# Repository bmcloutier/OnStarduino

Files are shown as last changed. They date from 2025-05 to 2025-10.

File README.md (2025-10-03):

# OnStarduino

#### Designed to appear as a retro-styled radio, this Arduino-powered dashboard displays data about my Chevy Bolt EV and lets me remotely start the car, unlock doors, and more!

Retro-styled portable cassette player OnStarduino

- The glowing tuner needle shows the battery level, and pulses if the car is charging.
- VU meter displays the current charging voltage of 120, 240, or 400 volts.
- Counter resets when data is refreshed and increments each hour thereafter.
- Buttons for play/rewind/etc send commands to remote start the car, unlock doors, flash lights, etc.
- Tape spins when a command is in progress, and the activity LED will blink SOS if the command fails.
- Toggle button enables an SMS reminder if the car isn't plugged in at 9PM.
- Slider controls the speaker volume, the knob adjusts LED brightness.
- Antenna is for aesthetics only!

<br>

## Project Highlights

- Communicates with the OnStar API to send commands and receive diagnostics. A separate VoIP API is used to send SMS notifications.
- Pseudo-multitasking allows concurrent tasks without a Real-Time OS (RTOS) on limited Arduino hardware.
- Several electro-mechanical features for inputs (keys and dials), outputs (LEDs and motors), and sensing (hall-effect rotary encoding).
- Designed in Fusion 360, 3D printed at home, assembled using mostly off-the-shelf electronics and one custom laser-cut part.

Special thanks to samrum for their work on the [OnStarJS](https://github.com/samrum/OnStarJS) library. It was instrumental in helping me understand the mechanics of the OnStar API.

[Icon artwork by Noah Jacobus](https://www.svgrepo.com/collection/chunk-16px-thick-interface-icons/)

<br>

## Minimum Install Requirements

:warning: **WARNING: This is an unofficial implementation of the OnStar API, use at your own risk.**

- An active [OnStar Connect](https://www.onstar.com/plans/connect) subscription and associated vehicle.
- An active [VoIP.ms](https://voip.ms/) account with a Direct Inward Dial (DID) number that support SMS ($0.99/month + $0.0075/SMS)
- [Arduino Nano ESP32](https://store.arduino.cc/products/nano-esp32) or similar Single Board Computer (SBC) with the following features:
  - WiFi
  - EEPROM with 2kB
  - 16 GPIO pins (4 must support PWM)
- Installed libraries:
  - [EEPROM](https://docs.arduino.cc/learn/built-in-libraries/eeprom/)
  - [ESP32Servo](https://madhephaestus.github.io/ESP32Servo/classServo.html)
  - [TimeLib](https://playground.arduino.cc/Code/Time/)
  - [WiFiClientSecure](https://github.com/pamelacece/WiFiClientSecure)
- Included `secrets.h`:

```cpp
#define SECRET_WIFI_SSID "aaa" // WiFi network name
#define SECRET_WIFI_PASS "bbb" // WiFi network password
#define SECRET_SMS_USER "someone@example.com" // VoIP.ms username
#define SECRET_SMS_PASS "password1" // VoIP.ms API password (not account password)
#define SECRET_SMS_DID "1234567890" // VoIP.ms DID number
#define SECRET_SMS_DST "9876543210" // Phone number to receive SMS notifications
#define SECRET_VIN "ccc" // Vehicle Identification Number (VIN) of your vehicle
#define SECRET_VID "hhh" // Vehicle Id from GM
#define SECRET_DEVICE_ID "dddddddd-dddd-dddd-dddd-dddddddddddd" // Random Version 4 UUID from https://www.uuidgenerator.net/version4
#define SECRET_CLIENT_REQUEST_ID "eeeeeeee-eeee-eeee-eeee-eeeeeeeeeeee" // Found in header of https request to custlogin.gm.com
#define SECRET_CLIENT_ID "ffffffff-ffff-ffff-ffff-ffffffffffff" // Found in body of https request to custlogin.gm.com
#define SECRET_REFRESH_TOKEN "ggg\0" // ~1650 character token found in https response from custlogin.gm.com
```

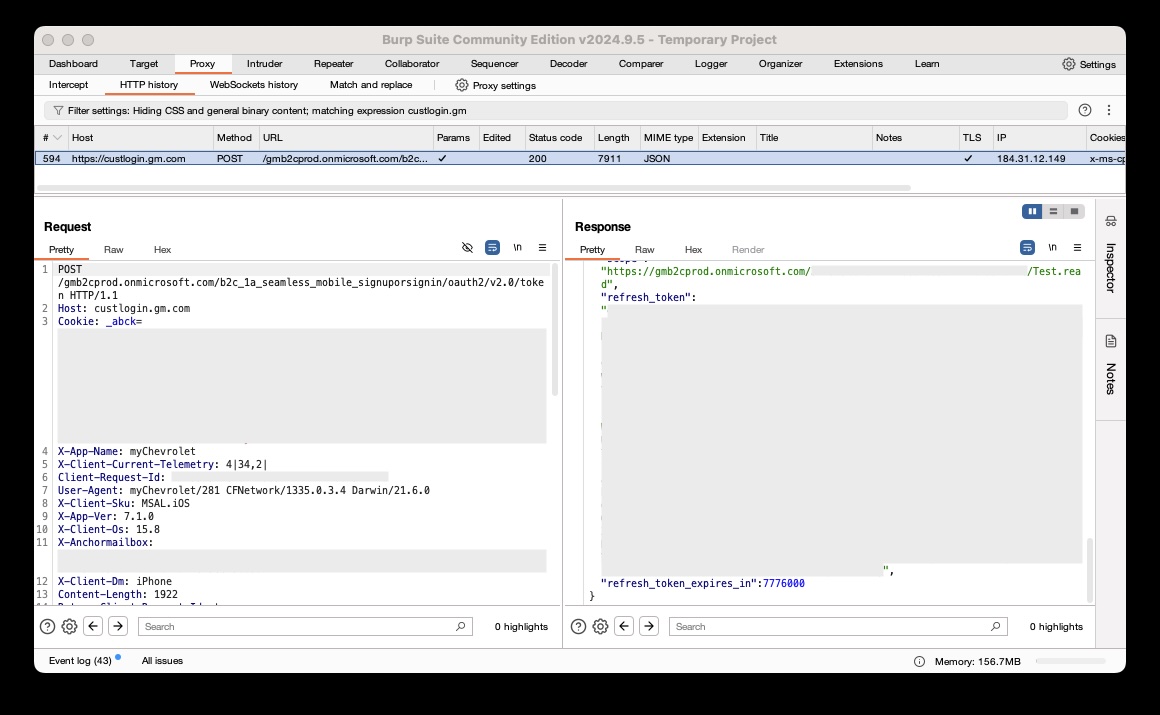
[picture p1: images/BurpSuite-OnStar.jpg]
Screenshot of Burp Suite interface
The last three secrets can be found by monitoring network traffic between the official Chevrolet app and custlogin.gm.com using a tool such as [Burp Suite](https://portswigger.net/). The critical request to custlogin.gm.com appears to occur only once an hour when the `subject_token` expires. Similarly, you can obtain your vehicle ID by monitoring traffic to eve-vcn.ext.gm.com.

<br>

## Component Details

### Tuner/Battery Level

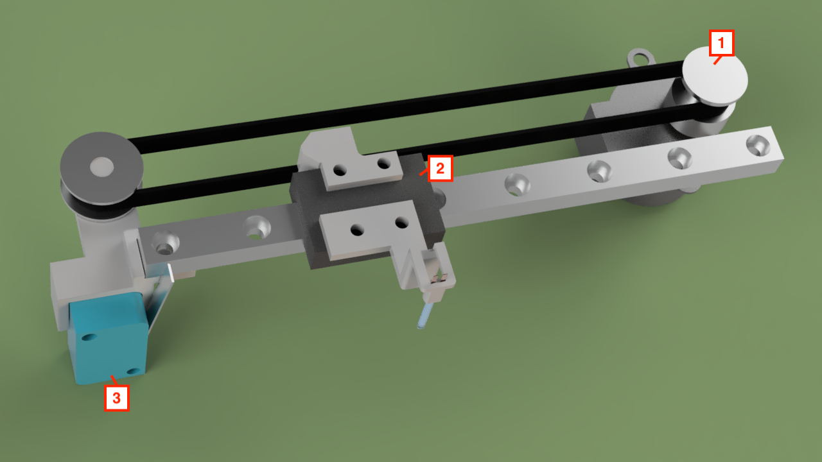
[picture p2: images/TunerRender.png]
Render of tuner mechanism
The tuner display is the easiest to read, even from across the room, so it shows the most important data: battery level. To move the tuner needle, a stepper motor rotates a pulley gear [1] attached to a belt, which moves the rail carriage [2] and the needle. The stop switch [3] is used to home the carriage at startup.

Moving an actual, physical object takes time, even if it's just turning a gear a fraction of a degree. Since the CPU will always outrun the motor, it's important to program delays to allow the motor to catch up. The following code moves the needle to the 0% battery position during setup, and includes a `stepperCooldown` variable that can be tweaked as needed. It turns out 2ms is the lowest whole millisecond that works; 1ms just makes the motor vibrate in a disconcerting way.

```cpp
for (int f = 0; f < 220; f++) {
  stepOnce(1);
  delay(stepperCooldown);
}
```

<br>

### Cassette Tape/Command in Progress

The radio wouldn't be complete without a tape player. I wanted its movement related to the command keys in some way, and eventually decided the tape should spin to indicate that a command is being processed. When it stops, you're clear to send another command.

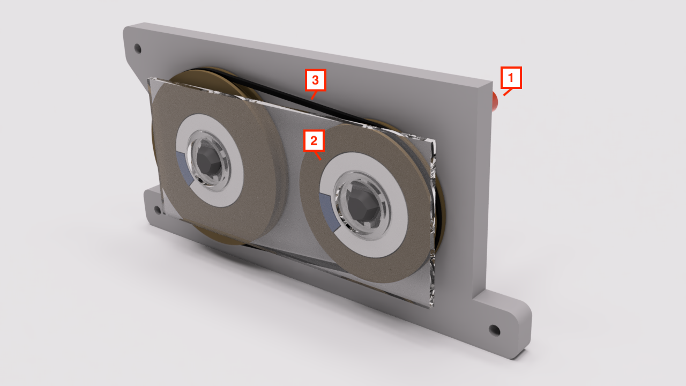
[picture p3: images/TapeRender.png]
Render of tape mechanism
A mini motor in the back [1] spins the right wheel [2]. A thin belt [3] connects the right wheel to the left. The wheels are different sizes, making them spin at slightly different rates for a realistic effect. The clear plastic is harvested from an actual tape since it's nearly impossible to 3D print crystal-clear objects.

<br>

### Tape Counter/Refresh Counter

Next to the tape player you'll often find a tape counter. On this radio it represents how many hours have elapsed since the last data refresh. Technically it increments on the hour like a cuckoo clock because the motor is a bit loud and having it run at random times was unacceptable.

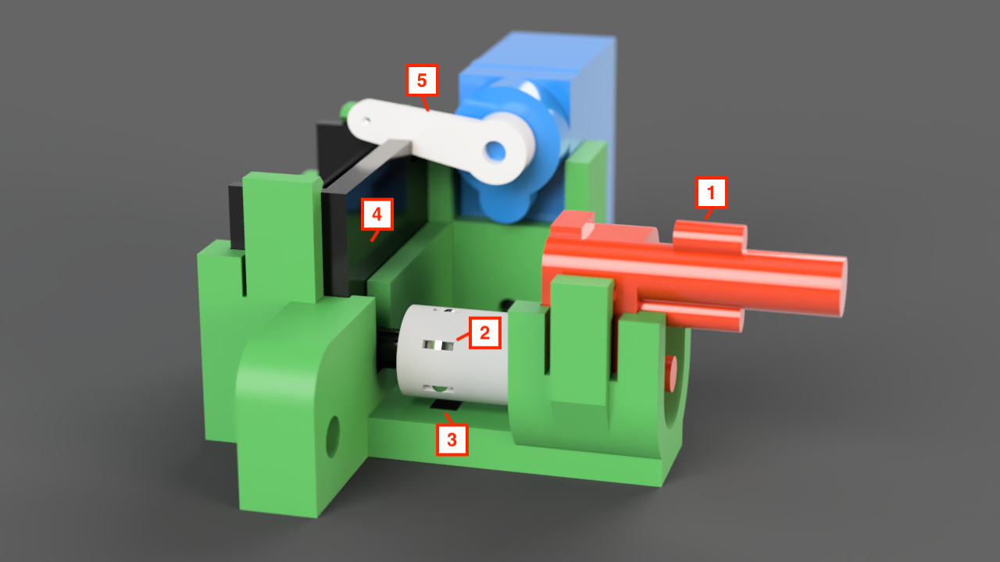
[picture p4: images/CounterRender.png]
Render of counter mechanism
The mini motor [1] spins a cuff [2] attached to a shaft. Embedded magnets pass over a hall effect sensor [3] as the shaft turns the gears of the counter mechanism [4]. The servo arm [5] lifts to reset the counter.

To roll the counter forward one digit the shaft must spin about 500 degrees, which means 8 passes of a magnet is not quite enough (480), but 9 is too much (540). The following code stops the motor from spinning after 8 passes, but only if the `hoursPassed` _isn't_ divisible by 4. That way, every fourth hour 9 magnets are allowed to pass, catching up the counter.

```cpp
if ((hoursPassed % 4 != 0 && counterPosition == 8) || counterPosition == 9) {
  digitalWrite(counterMotorPin, LOW);
  hoursPassed++;
  counterPosition = 0;
  isNewHour = false;
}
```

<br>

### Playback Controls/Command Keypad

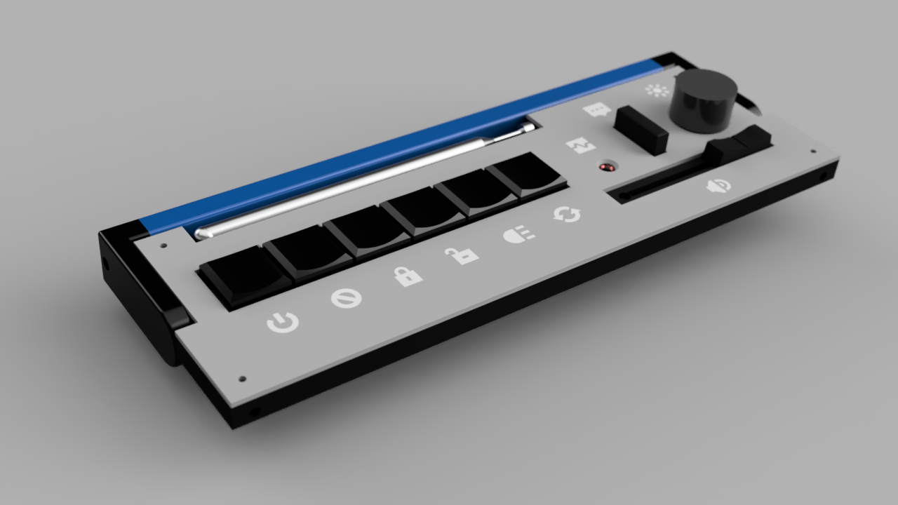
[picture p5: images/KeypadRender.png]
Render of keypad
The command keypad mimics the appearance of tape playback buttons, and uses mechanical keyboard switches for a nice look and feel. I wanted six buttons but didn't want to consume six GPIO pins, so I used a technique [posted by IoT_hobbyist](https://forum.arduino.cc/t/analog-keypad-or-multiple-buttons-on-a-single-arduino-pins-code-example/931236) that allows a single pin to read multiple button inputs.

The challenge with using the single-pin technique is that it relies on analog readings of the keypad, which is often noisy. For example, pressing a key might typically output a value of about 990. But sometimes that same key might output a value of 650. To mitigate this I sample the keypad every 5 milliseconds, counting how many times the value falls within a range. Only when a count exceeds a threshold will an event trigger. That way, one or two erroneous readings won't accidentally start my car!

```cpp
if (keypadValue > 2010 && keypadValue < 2040) {
  key1count++;
} else if (keypadValue > 1320 && keypadValue < 1340) {
  key2count++;
} else if (keypadValue > 980 && keypadValue < 1000) {
  key3count++;
} else if (keypadValue > 770 && keypadValue < 790) {
  key4count++;
} else if (keypadValue > 640 && keypadValue < 660) {
  key5count++;
} else if (keypadValue > 550 && keypadValue < 570) {
  key6count++;
}
```

<br>

## Assembly Resources

Although it's unlikely anyone would want to make one of these for themselves, below is a list of parts, 3D models, a wiring diagram, and an SVG for the display faces.

### Parts List

- Battery Indicator
  - [150mm MGN9 linear rail and carriage](https://www.amazon.com/dp/B0D54M2NR8)
  - [Stepper motor with driver board](<https://www.microcenter.com/product/639726/KS0327_Keyestudio_Stepper_Motor_Drive_Board__5V_Stepper_Motor_Kit_(3PCS)>)
  - [Micro switch](https://www.adafruit.com/product/818)
  - [6mm timing belt](<https://www.microcenter.com/product/661279/3D_Printer_Timing_Belt_(6mm)>)
  - [5x6mm 20T pully wheel](https://www.amazon.com/dp/B077GNZK3J)
  - [5x6mm idler wheel](https://www.amazon.com/dp/B07CCMQ8T7)
  - [25mm 3v blue filament LED](https://www.adafruit.com/product/6143)
  - [300mm 3v white filament LED](https://www.adafruit.com/product/6146)
  - [5k potentiometer](https://www.amazon.com/dp/B00GYVH0PW)
  - [Machined 20mm knob](https://www.adafruit.com/product/5527)
    <br>
    <br>
- Charge Voltage Display
  - [91C4 3V volt meter](https://www.amazon.com/dp/B08RNGGSWM)
    <br>
    <br>
- Refresh Counter
  - [3V mini DC motor](https://www.adafruit.com/product/3871)
  - [5V 9G servo](https://www.microcenter.com/product/613880/inland-blue-9g-servo-3-pack)
  - [3x1mm magnets](https://www.amazon.com/dp/B09MQ3JXLV)
  - [49E hall sensor](https://www.amazon.com/dp/B0CZ6RL4B2)
  - [Counter from Pioneer CT-760 tape deck](https://www.facebook.com/share/1CSfxKRXxj/)
    <br>
    <br>
- Cassette Tape
  - [3V mini DC motor](https://www.adafruit.com/product/3871)
  - [7mm x 14mm x 5mm bearings](https://www.amazon.com/dp/B07FPNWBL6)
  - [1mm rubber belt](https://www.amazon.com/dp/B077FNY4H1)
  - [Maxell cassette tape](https://www.amazon.com/dp/B000001OKK)
  - [1mm felt sheets](https://www.amazon.com/dp/B01GCLS32M)
    <br>
    <br>
- Command Keypad
  - [Linear keyboard switches](https://www.microcenter.com/product/674879/MX_Heavy_Black_RGB__Linear_Key_Switches)
  - [Low profile keycaps](https://mechanicalkeyboards.com/products/tai-hao-black-tht-blank-18-key-abs-low-profile)
    <br>
    <br>
- Speaker
  - [1w 8 ohm speaker](https://www.adafruit.com/product/5986)
  - [5k slide potentiometer](https://www.amazon.com/dp/B07W3WRZH2)
    <br>
    <br>
- Electronics
  - [Arduino Nano ESP32](https://store.arduino.cc/collections/nano-family/products/nano-esp32)
  - [Mini breadboard](https://www.microcenter.com/product/504160/Perma-Proto_Mint_Tin_Size_Breadboard_PCB)
  - [TIP120 transistors](https://www.amazon.com/dp/B08BFYYK7D)
  - [0.1mF capacitor](https://www.microcenter.com/product/603754/Pi_Kit_Deluxe_Parts_Pack)
  - [3v LED](https://www.microcenter.com/product/632687/5mm_5_Colors_LED_Light_Emitting_Diode_Assortment_Kit_-_500_Pcs)
  - [Assorted resistors](https://www.amazon.com/dp/B0792M83JH)
  - [Toggle switch](https://www.amazon.com/dp/B07PK6C6LB)
  - [USB-C extension](https://www.adafruit.com/product/6069)
    <br>
    <br>
- Housing
  - [0.5mm clear PET sheet](https://www.amazon.com/dp/B0CT9W4QFD)
  - [Ocean Blue PLA](https://www.amazon.com/dp/B01DXWROBO)
  - [Carbon Fiber PLA](<https://www.microcenter.com/product/632387/175mm_PLA_Pro_3D_Printer_Filament_10_kg_(22_lbs)_Spool_-_Carbon_Fiber;_Tough,_High_Rigidity>)
  - [Gray PLA](<https://www.microcenter.com/product/606620/175mm_PLA_3D_Printer_Filament_1kg_(22_lbs)_Cardboard_Spool_-_Gray;_Dimensional_Accuracy_--_003mm,_Fits_Most_FDM-FFF_Printers,_Odor_Free,_Clog_Free>)
  - [Brown PLA](<https://www.microcenter.com/product/611536/175mm_Brown_PLA_3D_Printer_Filament_-_1kg_Spool_(22_lbs)>)
  - [White PLA](<https://www.microcenter.com/product/611544/inland-175mm-pla-3d-printer-filament-10-kg-(22-lbs)-spool-white>)
  - [M2 & M3 heat-set inserts](https://www.amazon.com/dp/B08BCRZZS3)
  - [M2 & M3 screws](https://www.amazon.com/dp/B0BNJMTQVX)
    <br>
    <br>
- Aesthetics
  - [Chevrolet EV enamel pin](https://chevycollection.com/products/chevy-ev-lapel-pin?variant=43225981714630)
  - [Chevrolet bowtie enamel pin](https://chevycollection.com/products/copy-of-chevy-gold-bowtie-lapel-pin-1?variant=43225999507654)
  - [130mm telescoping antenna](https://www.amazon.com/dp/B00W8WL980)
  - 1.5mm laser-cut brushed aluminum front [STEP file](/resources/AluminumFront.step) from [pcbway.com](https://www.pcbway.com)

### Files

- [3MFs for 3D printing](/resources/models)
- [SVG for 2D printing](/resources/DisplayFaces.svg)
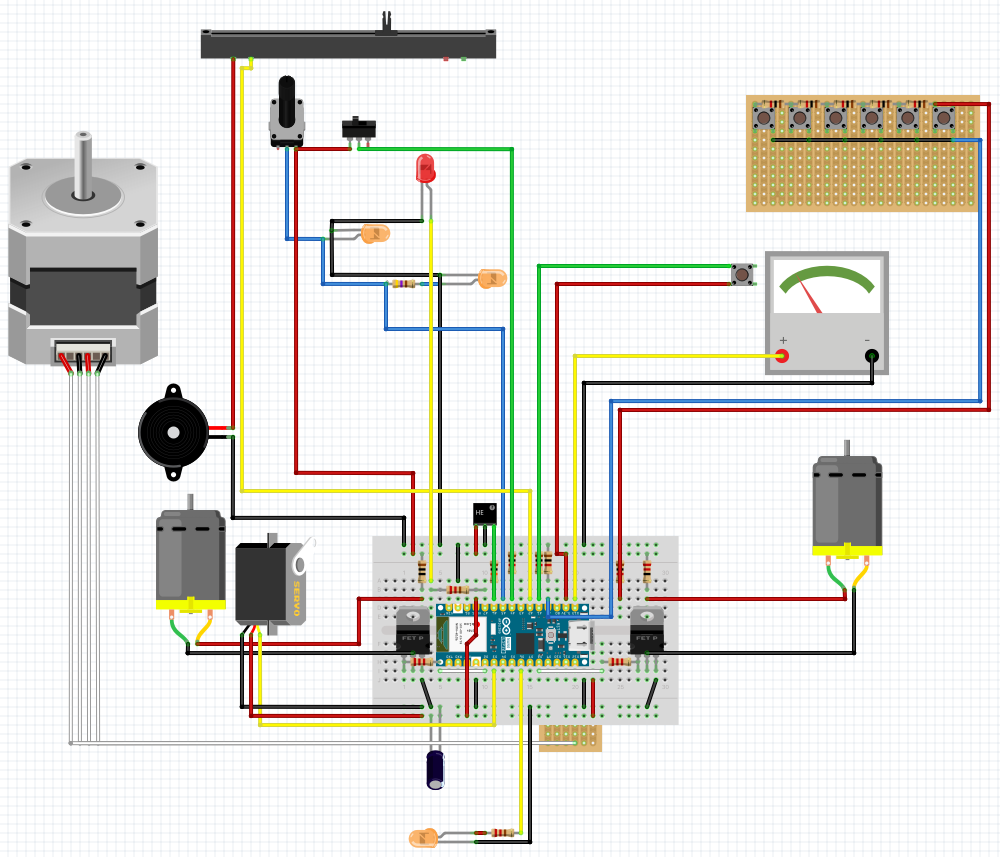
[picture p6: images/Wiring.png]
Full wiring diagram
- [Fritzing wiring diagram](/resources/WiringDiagram.fzz)

<br>

## Future Improvements

- Allow wifi details to be set through serial interface and/or bluetooth
- Implement one-time password login as seen in [OnStarJS2](https://github.com/BigThunderSR/OnStarJS) so network sniffing isn't required
- Switch to OBD-II option such as [mictrack](https://shop.mictrack.com/product/4g-obd-gps-tracker-mp91/) for direct vehicle connection through the network provider of my choice (no OnStar subscription, possibly no VoIP subscription either)

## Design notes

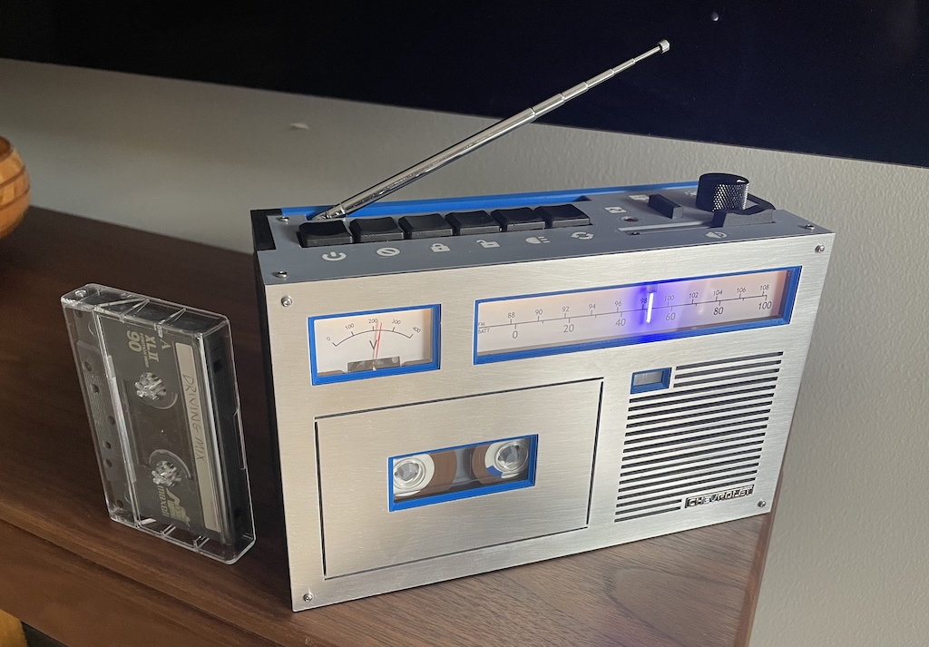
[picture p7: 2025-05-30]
images/OnStarduino.jpg

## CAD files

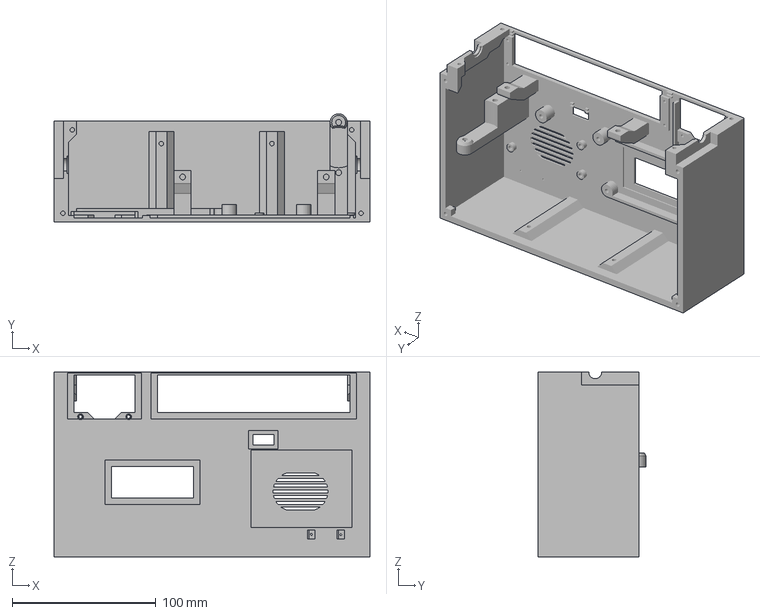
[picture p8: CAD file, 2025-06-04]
resources/models/Housing_Main.3mf
220.0 x 75.5 x 128.5 mm

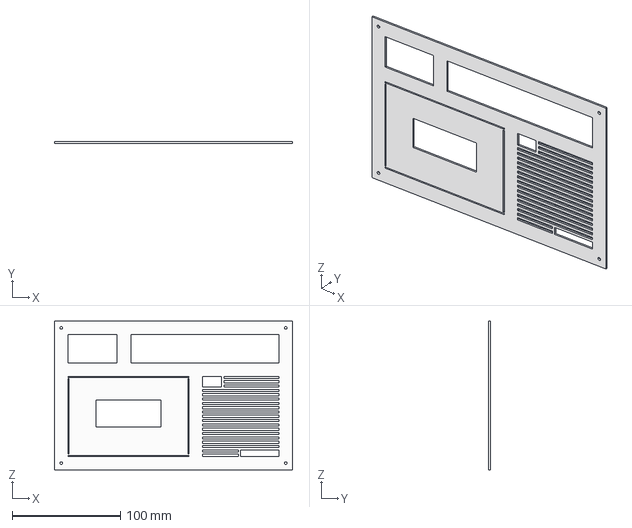
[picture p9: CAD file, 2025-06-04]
resources/AluminumFront.step
220.0 x 1.50 x 137.5 mm

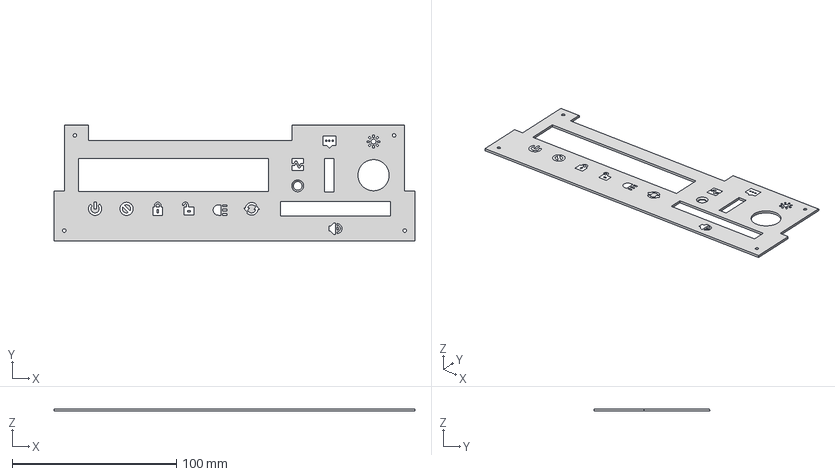
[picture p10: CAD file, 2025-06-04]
resources/models/Surface_Top.3mf
220.0 x 70.5 x 1.50 mm
Activity1
Activity2
Bright1
Bright2
Bright3
Bright4
Bright5
Bright6
Bright7
Bright8
Bright9
Flash1
Flash2
Flash3
Flash4
Lock
Message
Power1
Power2
Refresh1
Refresh2
Sound1
Sound2
Sound3
Stop
Surface
Unlock

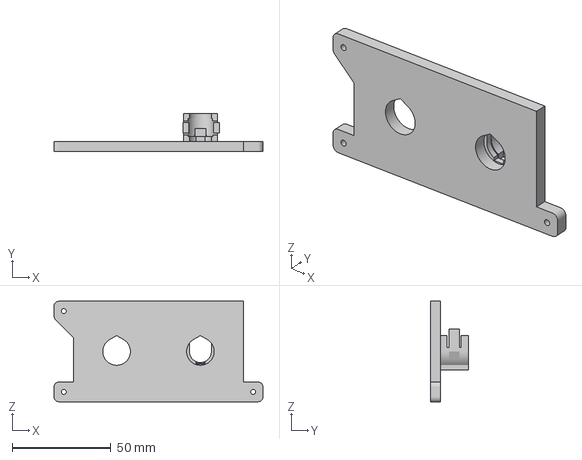
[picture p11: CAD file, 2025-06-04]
resources/models/Tape_Frame.3mf
106.0 x 19.1 x 51.0 mm

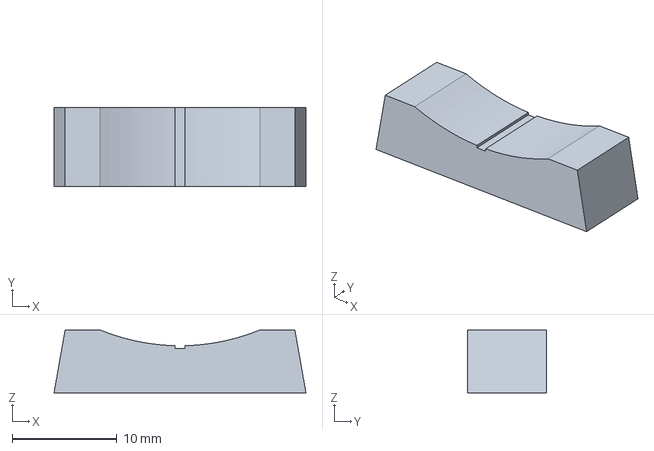
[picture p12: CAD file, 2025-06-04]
resources/models/Speaker_Slider.3mf
24.0 x 7.50 x 6.00 mm

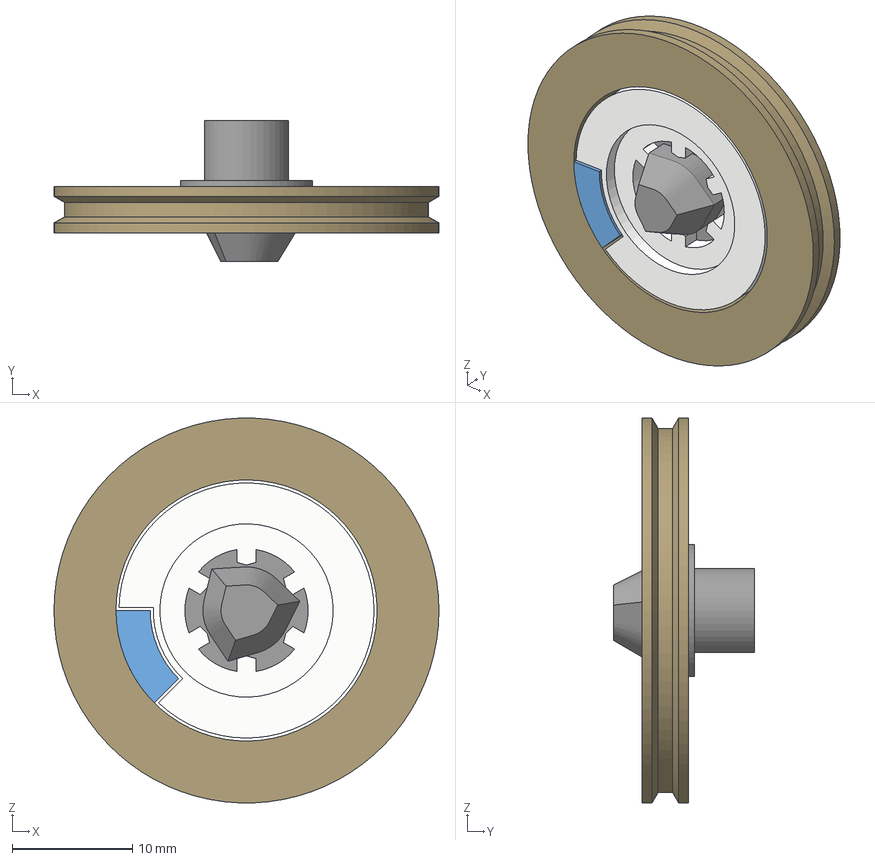
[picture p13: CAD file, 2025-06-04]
resources/models/Tape_RightWheel.3mf
32.0 x 11.8 x 32.0 mm
BlackTurner
BrownTape
OrangePlug
WhiteHub

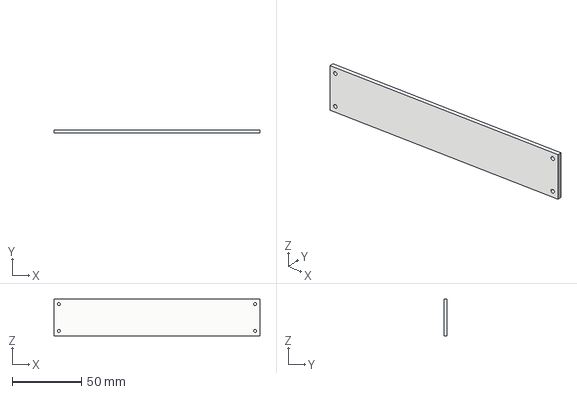
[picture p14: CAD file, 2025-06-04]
resources/models/Tuner_FacePlate.3mf
149.0 x 2.45 x 26.5 mm

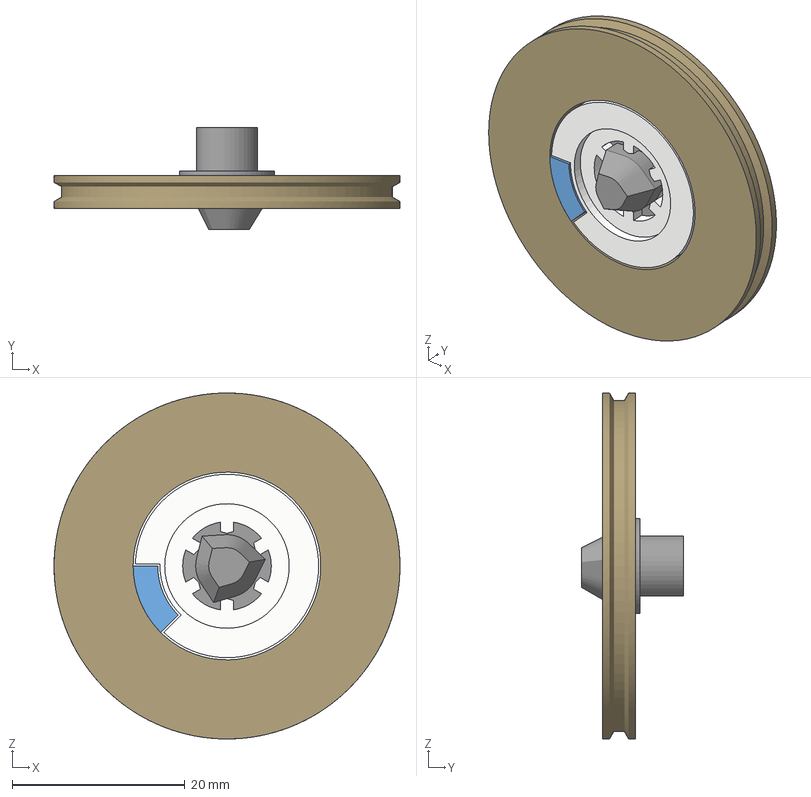
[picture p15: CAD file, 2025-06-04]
resources/models/Tape_LeftWheel.3mf
40.0 x 11.8 x 40.0 mm
BlackTurner (1)
BrownTape (1)
OrangePlug (1)
WhiteHub (1)

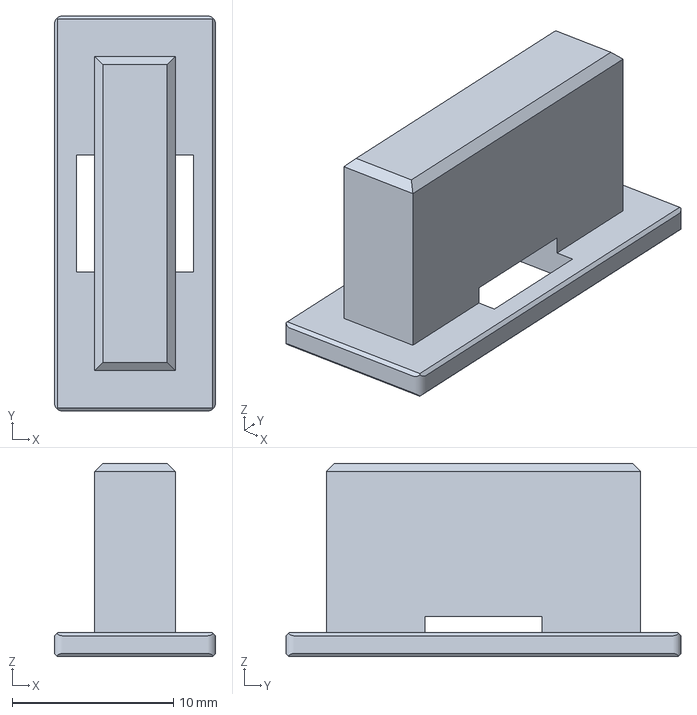
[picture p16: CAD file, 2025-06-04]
resources/models/SMS_Toggle.3mf
10.0 x 24.5 x 12.0 mm

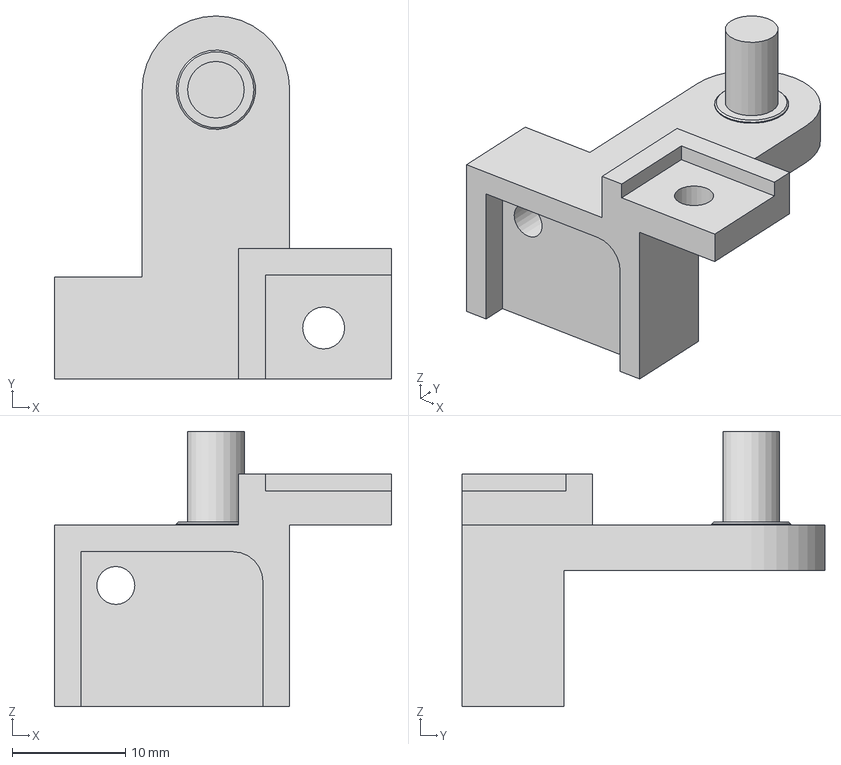
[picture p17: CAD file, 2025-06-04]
resources/models/Tuner_Endstop.3mf
29.8 x 32.0 x 24.2 mm

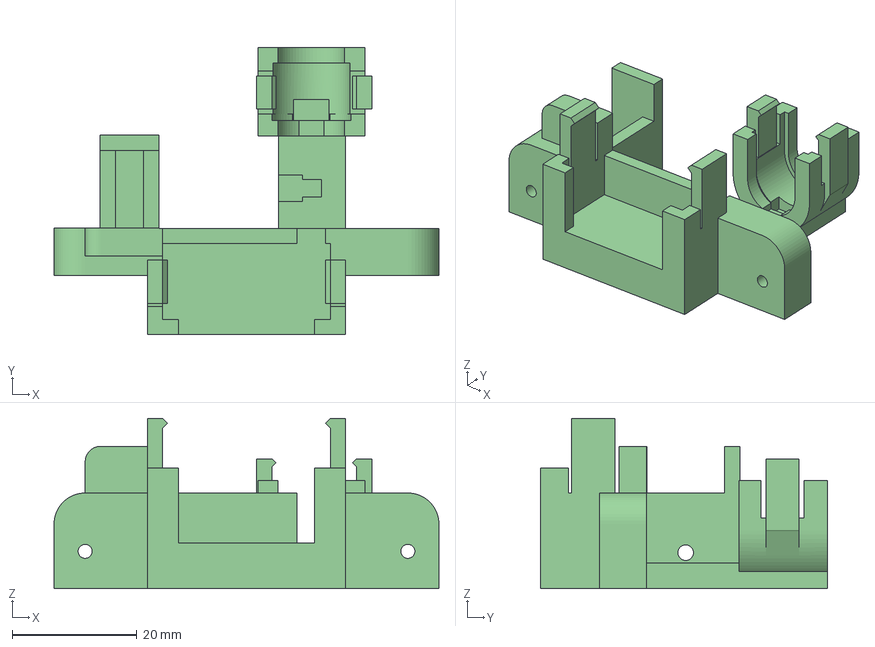
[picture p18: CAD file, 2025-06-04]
resources/models/Counter_Frame.3mf
61.9 x 46.1 x 27.4 mm

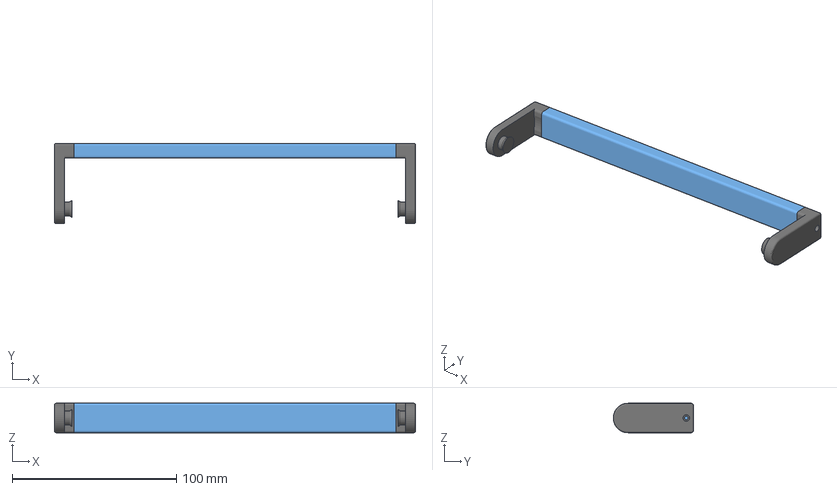
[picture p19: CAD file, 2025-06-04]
resources/models/Housing_Handle.3mf
220.0 x 49.0 x 18.0 mm
Handle
LeftArm
RightArm

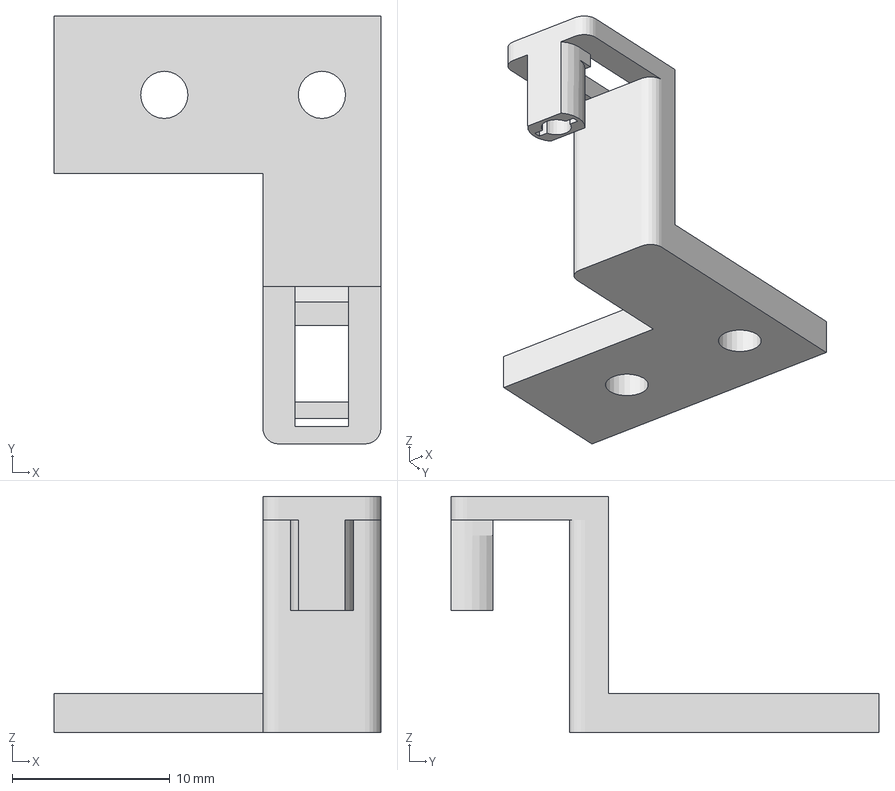
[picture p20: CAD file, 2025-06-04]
resources/models/Tuner_NeedleHolder.3mf
20.8 x 27.1 x 15.0 mm

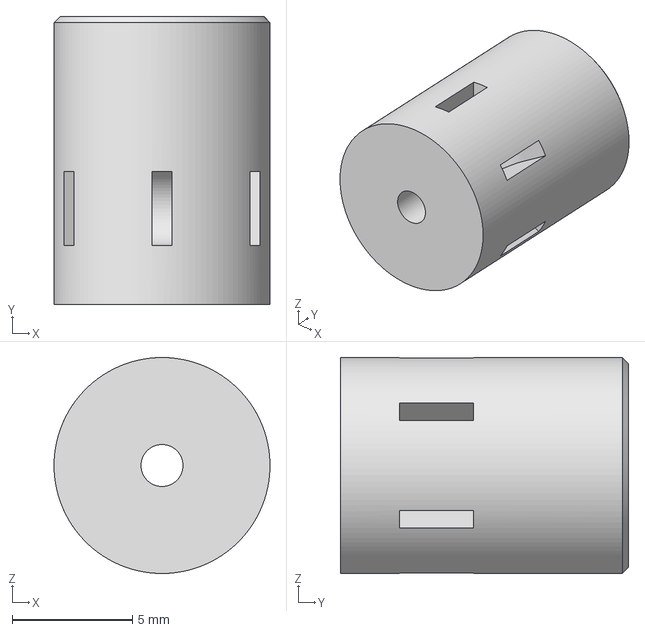
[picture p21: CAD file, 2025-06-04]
resources/models/Counter_Cuff.3mf
9.00 x 12.0 x 9.00 mm

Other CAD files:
resources/models/Surface_Face.3mf
resources/models/Housing_Top.3mf
resources/models/Tuner_BeltHolder.3mf
resources/models/Housing_Back.3mf
resources/models/Housing_WindowBorders.3mf

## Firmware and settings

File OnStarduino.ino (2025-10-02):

#include <EEPROM.h>
#include <ESP32Servo.h>
#include <TimeLib.h>
#include <WiFiClientSecure.h>

#include "secrets.h"

//
// PIN CONSTANTS
const int keypadPin = 17;       // A0 INPUT
const int dialPin = 22;         // A5 INPUT
const int smsPin = 21;          // A4 INPUT PULLUP
const int voltagePin = 13;      // D13 PWM OUTPUT
const int counterServoPin = 3;  // D3 PWM OUTPUT
const int counterMotorPin = 2;  // D2 OUTPUT
const int hallSensorPin = 23;   // A6 INPUT
const int stepperPin1 = 9;      // D9 OUTPUT
const int stepperPin2 = 10;     // D10 OUTPUT
const int stepperPin3 = 11;     // D11 OUTPUT
const int stepperPin4 = 12;     // D12 OUTPUT
const int stepperStopPin = 18;  // A1 INPUT PULLUP
const int tapeMotorPin = 8;     // D8 OUTPUT
const int speakerPin = 19;      // A2 PWM OUTPUT
const int batteryLEDPin = 6;    // D6 PWM OUTPUT
const int statusLEDPin = 24;    // A7 PWM OUTPUT

//
// SECRET VARIABLES
char mobileSSID[] = SECRET_MOBILE_SSID;
char wifiSSID[] = SECRET_WIFI_SSID;
char wifiPass[] = SECRET_WIFI_PASS;
char smsUser[] = SECRET_SMS_USER;
char smsPass[] = SECRET_SMS_PASS;
char smsDID[] = SECRET_SMS_DID;
char smsDST[] = SECRET_SMS_DST;
char vin[] = SECRET_VIN;
char vid[] = SECRET_VID;
char deviceID[] = SECRET_DEVICE_ID;
char clientRequestID[] = SECRET_CLIENT_REQUEST_ID;
char clientID[] = SECRET_CLIENT_ID;

//
// GENERAL VARIABLES
unsigned long currentMillis = 0;
int failState = 0;

//
// COMMUNICATIONS VARIABLES
WiFiClientSecure client;
char smsServer[] = "voip.ms";
char refreshServer[] = "custlogin.gm.com";
char apiServer[] = "na-mobile-api.gm.com";
char queryServer[] = "eve-vcn.ext.gm.com";
int port = 443;
int refreshTokenLength = 0;
int subjectTokenLength = 0;
int accessTokenLength = 0;
int refreshTokenAddress = 10;
char refreshToken[1660] = SECRET_REFRESH_TOKEN;
char subjectToken[1725] = {0};
char accessToken[1600] = {0};
char gmToken[400] = {0};
long refreshTokenTimestamp = 0;
long subjectTokenTimestamp = 0;
long accessTokenTimestamp = 0;
long gmTokenTimestamp = 0;
int collectIndex = 0;
char collect = false;
char timeCollection[59];
char subjectCollection[6000] = {0};
char accessCollection[2000] = {0};
char gmCollection[600] = {0};
char commandCollection[300] = {0};
char responseCollection[1500] = {0};
char commandID[50] = {0};
int queuedRequest = 0;
int queuedFetch = 0;
unsigned long commandURLStamp = 0;
unsigned long diagnosticStamp = 0;
unsigned long dailyStamp = 0;
unsigned long weeklyStamp = 0;
unsigned long alertStamp = 0;
unsigned long sendStamp = 0;

// KEYPAD VARIABLES
int keypadValue = 0;
unsigned long keyStamp = 0;
int key1count = 0;
int key2count = 0;
int key3count = 0;
int key4count = 0;
int key5count = 0;
int key6count = 0;
int keySampleCooldown = 5;
int queuedCommand = 0;

//
// EV VARIABLES
int evBatteryLevel = 0;
int evPlugVoltage = 0;
bool isEVCharging = false;
bool isEVPlugged = false;

//
// VOLTMETER VARIABLES
bool setVoltage = false;

//
// LED VARIABLES
bool isTransmitting = false;
unsigned long batteryLEDStamp = 0;
float batteryLEDBrightness = 10.0;
int dialValue = 0;
int rollingDialValues[] = {0, 0, 0, 0, 0, 0, 0, 0, 0};
int dialElement = 0;
int dialAverage = 0;
int stickyDialAverage = 0;
unsigned long dialStamp = 0;
float brightnessMultiplier = 0.0;
bool increaseBrightness = true;
unsigned long statusLEDStamp = 0;
int statusLEDIncrement = 2;
byte statusLEDBrightness = 0;

//
// STEPPER VARIABLES
unsigned long stepperStamp = 0;
const int stepsTo100 = 5600;
int stepperCooldown = 2;
int stepperTarget = 0;
int stepperValue = 0;
int stepperStep = 0;

//
// COUNTER VARIABLES
Servo counterservo;
unsigned long servoStamp = 0;
unsigned long counterStamp = 0;
unsigned long hourStamp = 0;
bool isResetRequired = true;
bool isServoRaised = false;
bool isNewHour = false;
bool wasLastSampleHigh = false;
int servoCooldown = 500;
int counterPosition = 0;
int hoursPassed = 0;

//
// SETUP
void setup() {
  Serial.begin(115200);

  // KEYPAD SETUP
  pinMode(keypadPin, INPUT);

  // COUNTER SERVO/MOTOR/SENSOR SETUP
  ESP32PWM::allocateTimer(0);
  ESP32PWM::allocateTimer(1);
  ESP32PWM::allocateTimer(2);
  ESP32PWM::allocateTimer(3);
  counterservo.setPeriodHertz(50);
  counterservo.attach(counterServoPin);
  pinMode(counterMotorPin, OUTPUT);
  pinMode(hallSensorPin, INPUT);
  while (digitalRead(hallSensorPin) == HIGH) {
    digitalWrite(counterMotorPin, HIGH);
  }
  digitalWrite(counterMotorPin, LOW);

  // BATTERY/STATUS LED SETUP
  pinMode(dialPin, INPUT);
  pinMode(batteryLEDPin, OUTPUT);
  pinMode(statusLEDPin, OUTPUT);
  analogWrite(batteryLEDPin, batteryLEDBrightness);

  // STEPPER/STOP SWITCH SETUP
  pinMode(stepperPin1, OUTPUT);
  pinMode(stepperPin2, OUTPUT);
  pinMode(stepperPin3, OUTPUT);
  pinMode(stepperPin4, OUTPUT);
  pinMode(stepperStopPin, INPUT_PULLUP);

  while (digitalRead(stepperStopPin) == LOW) {
    stepOnce(-1);
    delay(stepperCooldown);
  }
  for (int f = 0; f < 220; f++) {
    stepOnce(1);
    delay(stepperCooldown);
  }
  digitalWrite(stepperPin1, 0);
  digitalWrite(stepperPin2, 0);
  digitalWrite(stepperPin3, 0);
  digitalWrite(stepperPin4, 0);

  // SMS TOGGLE SETUP
  pinMode(smsPin, INPUT);

  // TAPE MOTOR SETUP
  pinMode(tapeMotorPin, OUTPUT);

  // SPEAKER SETUP
  pinMode(speakerPin, OUTPUT);
  setToneChannel(6);

  // VOLTMETER SETUP
  pinMode(voltagePin, OUTPUT);

  // WIFI SETUP
  WiFi.begin(wifiSSID, wifiPass);
  isTransmitting = true;
  while (WiFi.status() != WL_CONNECTED) {
    currentMillis = millis();
    setStatusLED();
  }
  isTransmitting = false;
  setStatusLED();

  // TIME UPDATE
  client.setInsecure();
  isTransmitting = true;
  client.connect(smsServer, port);
  while (!client.connected()) {
    delay(10);
  }
  queuedRequest = 11;
  sendRequest();
  while (client.available() < 200) {
    delay(10);
  }
  fetchResponse();
  updateTime();
  Serial.println(now());

  if (timeStatus() == timeNotSet) {
    blinkSOS();
  }

  // EEPROM SETUP
  EEPROM.begin(1670);
  EEPROM.get(0, refreshTokenTimestamp);
  Serial.println(refreshTokenTimestamp);
  if (refreshTokenTimestamp > 0) {
    EEPROM.get(10, refreshToken);
  }
  for (int l = 0; l < sizeof(refreshToken); l++) {
    if (refreshToken[l] == NULL) {
      refreshTokenLength = l;
      break;
    }
  }
}

//
// LOOP
void loop() {
  currentMillis = millis();
  handleErrors();
  queueDiagnosticCommand();
  sendAlert();
  sampleKeypad();
  queueKeypadCommand();
  handleCommand();
  sendRequest();
  fetchResponse();
  quanitzeDial();
  setBatteryLED();
  setStatusLED();
  setVoltmeter();
  setStepper();
  resetCounter();
  incrementCounter();
}

//
// FUNCTIONS

void handleErrors() {
  if (failState > 0) {
    if (WiFi.isConnected()) {
      client.connect(smsServer, port);
      client.print("GET /api/v1/rest.php?api_username=");
      client.print(smsUser);
      client.print("&api_password=");
      client.print(smsPass);
      client.print("&method=sendSMS&did=");
      client.print(smsDID);
      client.print("&dst=");
      client.print(smsDST);
      client.print("&message=Error: ");
    }
    Serial.print("ERROR: ");
    switch (failState) {
      case 1: {
        client.print("Initial connection failed");
        Serial.println("Initial connection failed");
        break;
      }
      case 2: {
        client.print("Response took too long to arrive");
        Serial.println("Response took too long to arrive");
        break;
      }
      case 3: {
        client.print("Command ID not received");
        Serial.println("Command ID not received");
        Serial.println(commandCollection);
        break;
      }
      case 4: {
        client.print("Unexpected command result");
        Serial.println("Unexpected command result");
        Serial.println(responseCollection);
        break;
      }
      case 5: {
        client.print("Failed refresh or subject token update");
        Serial.println("Failed refresh or subject token update");
        Serial.println(subjectCollection);
        break;
      }
      case 6: {
        client.print("Failed access token update");
        Serial.println("Failed access token update");
        Serial.println(accessCollection);
        break;
      }
      case 7: {
        client.print("Failed to get date");
        Serial.println("Failed to get date");
        Serial.println(timeCollection);
        break;
      }
      case 8: {
        client.print("Invalid battery level");
        Serial.println("Invalid battery level");
        Serial.println(responseCollection);
        break;
      }
      case 9: {
        client.print("Invalid plug voltage");
        Serial.println("Invalid plug voltage");
        Serial.println(responseCollection);
        break;
      }
      case 10: {
        client.print("Invalid plug state");
        Serial.println("Invalid plug state");
        Serial.println(responseCollection);
        break;
      }
      case 11: {
        client.print("Invalid charge state");
        Serial.println("Invalid charge state");
        Serial.println(responseCollection);
        break;
      }
      case 12: {
        client.print("Failed gm token update");
        Serial.println("Failed gm token update");
        Serial.println(gmCollection);
        break;
      }
    }
    client.println(" HTTP/1.1");
    client.println("Host: voip.ms");
    client.println();
    delay(2000);
    client.flush();
    client.stop();
  }
  failState = 0;
}

void queueDiagnosticCommand() {
  if (queuedCommand == 0) {
    if (isEVCharging && currentMillis - diagnosticStamp >= 3600000) {
      Serial.println("isEVCharging diagnostics request");
      queuedCommand = 6;
    } else if (digitalRead(smsPin) == HIGH && hour() == 2 && (currentMillis - dailyStamp > 3600000 || dailyStamp == 0)) {
      Serial.println("nightly diagnostics request");
      // 2:00GMT/21:00CDT
      dailyStamp = currentMillis;
      queuedCommand = 6;
    } else if (weekday() == 7 && hour() == 13 && (currentMillis - weeklyStamp > 3600000 || weeklyStamp == 0)) {
      Serial.println("weekly diagnostics request");
      // Saturday at 13:00GMT/8:00CDT
      weeklyStamp = currentMillis;
      queuedCommand = 6;
    }
  }
}

void sendAlert() {
  if (queuedCommand == 0 && digitalRead(smsPin) == HIGH && !isEVPlugged && evBatteryLevel < 80 && dailyStamp > alertStamp) {
    alertStamp = currentMillis;
    client.connect(smsServer, port);
    queuedRequest = 10;
    isTransmitting = true;
  }
}

void sampleKeypad() {
  if (!isTransmitting && queuedRequest == 0 && currentMillis - keyStamp >= keySampleCooldown) {
    keyStamp = currentMillis;
    keypadValue = analogRead(keypadPin);
    if (keypadValue > 2010 && keypadValue < 2040) {
      key1count++;
    } else if (keypadValue > 1320 && keypadValue < 1340) {
      key2count++;
    } else if (keypadValue > 980 && keypadValue < 1000) {
      key3count++;
    } else if (keypadValue > 770 && keypadValue < 790) {
      key4count++;
    } else if (keypadValue > 640 && keypadValue < 660) {
      key5count++;
    } else if (keypadValue > 550 && keypadValue < 570) {
      key6count++;
    }
  }
}

void queueKeypadCommand() {
  if (queuedCommand == 0) {
    if (key1count > 2) {
      Serial.println("keypad 1");
      queuedCommand = 1;
      resetKeyCount();
    } else if (key2count > 2) {
      Serial.println("keypad 2");
      queuedCommand = 2;
      resetKeyCount();
    } else if (key3count > 2) {
      Serial.println("keypad 3");
      queuedCommand = 3;
      resetKeyCount();
    } else if (key4count > 2) {
      Serial.println("keypad 4");
      queuedCommand = 4;
      resetKeyCount();
    } else if (key5count > 2) {
      Serial.println("keypad 5");
      queuedCommand = 5;
      resetKeyCount();
    } else if (key6count > 2) {
      Serial.println("keypad 6");
      queuedCommand = 6;
      resetKeyCount();
    }
    if (queuedCommand > 0) {
      digitalWrite(tapeMotorPin, HIGH);
    }
  }
}

void handleCommand() {
  if (queuedCommand > 0 && !isTransmitting) {
    if (now() - subjectTokenTimestamp >= 3600 - 60) {
      client.connect(refreshServer, port);
      queuedRequest = 8;
      Serial.println("queuedRequest 8");
    } else if (now() - accessTokenTimestamp >= 1800 - 60) {
      client.connect(apiServer, port);
      queuedRequest = 9;
      Serial.println("queuedRequest 9");
    } else if (queuedCommand == 6 && now() - gmTokenTimestamp >= 1800 - 60) {
      client.connect(queryServer, port);
      queuedRequest = 12;
      Serial.println("queuedRequest 12");
    } else if (queuedCommand == 6) {
      client.connect(queryServer, port);
      queuedRequest = queuedCommand;
      Serial.println("queuedRequest 6");
    } else if (queuedCommand != 7) {
      client.connect(apiServer, port);
      queuedRequest = queuedCommand;
      Serial.println("queuedRequest !7");
    } else if (queuedCommand == 7 && currentMillis - commandURLStamp > 5000) {
      commandURLStamp = currentMillis;
      client.connect(apiServer, port);
      queuedRequest = 7;
      Serial.println("queuedRequest 7");
    }
    if (queuedRequest > 0) {
      isTransmitting = true;
    }
    if (queuedRequest > 0 && client.connected() == false) {
      failState = 1;
    }
  }
}

void sendRequest() {
  if (client.connected() && queuedRequest > 0) {
    switch (queuedRequest) {
      // START
      case 1: {
        Serial.println("sendRequest 1");
        client.print("POST /api/v1/account/vehicles/");
        client.print(vin);
        client.println("/commands/start HTTP/1.1");
        client.println("Accept: application/json");
        client.println("Accept-Encoding: br, gzip, deflate");
        client.println("Accept-Language: en-US");
        client.print("Authorization: Bearer ");
        client.println(accessToken);
        client.println("Connection: keep-alive");
        client.println("Content-Type: application/json; charset=UTF-8");
        client.println("Host: na-mobile-api.gm.com");
        client.println("User-Agent: myChevrolet/118 CFNetwork/1408.0.4 Darwin/22.5.0");
        client.println("Content-Length: 0");
        client.println();
        break;
      }

      // STOP
      case 2: {
        Serial.println("sendRequest 2");
        client.print("POST /api/v1/account/vehicles/");
        client.print(vin);
        client.println("/commands/cancelStart HTTP/1.1");
        client.println("Accept: application/json");
        client.println("Accept-Encoding: br, gzip, deflate");
        client.println("Accept-Language: en-US");
        client.print("Authorization: Bearer ");
        client.println(accessToken);
        client.println("Connection: keep-alive");
        client.println("Content-Type: application/json; charset=UTF-8");
        client.println("Host: na-mobile-api.gm.com");
        client.println("User-Agent: myChevrolet/118 CFNetwork/1408.0.4 Darwin/22.5.0");
        client.println("Content-Length: 0");
        client.println();
        break;
      }

      // LOCK
      case 3: {
        Serial.println("sendRequest 3");
        client.print("POST /api/v1/account/vehicles/");
        client.print(vin);
        client.println("/commands/lockDoor HTTP/1.1");
        client.println("Accept: application/json");
        client.println("Accept-Encoding: br, gzip, deflate");
        client.println("Accept-Language: en-US");
        client.print("Authorization: Bearer ");
        client.println(accessToken);
        client.println("Connection: keep-alive");
        client.println("Content-Type: application/json; charset=UTF-8");
        client.println("Host: na-mobile-api.gm.com");
        client.println("User-Agent: myChevrolet/118 CFNetwork/1408.0.4 Darwin/22.5.0");
        client.println("Content-Length: 34");
        client.println();
        client.println("{\"lockDoorRequest\": { \"delay\": 0}}");
        break;
      }

      // UNLOCK
      case 4: {
        Serial.println("sendRequest 4");
        client.print("POST /api/v1/account/vehicles/");
        client.print(vin);
        client.println("/commands/unlockDoor HTTP/1.1");
        client.println("Accept: application/json");
        client.println("Accept-Encoding: br, gzip, deflate");
        client.println("Accept-Language: en-US");
        client.print("Authorization: Bearer ");
        client.println(accessToken);
        client.println("Connection: keep-alive");
        client.println("Content-Type: application/json; charset=UTF-8");
        client.println("Host: na-mobile-api.gm.com");
        client.println("User-Agent: myChevrolet/118 CFNetwork/1408.0.4 Darwin/22.5.0");
        client.println("Content-Length: 36");
        client.println();
        client.println("{\"unlockDoorRequest\": { \"delay\": 0}}");
        break;
      }

      // FLASH
      case 5: {
        Serial.println("sendRequest 5");
        client.print("POST /api/v1/account/vehicles/");
        client.print(vin);
        client.println("/commands/alert HTTP/1.1");
        client.println("Accept: application/json");
        client.println("Accept-Encoding: br, gzip, deflate");
        client.println("Accept-Language: en-US");
        client.print("Authorization: Bearer ");
        client.println(accessToken);
        client.println("Connection: keep-alive");
        client.println("Content-Type: application/json; charset=UTF-8");
        client.println("Host: na-mobile-api.gm.com");
        client.println("User-Agent: myChevrolet/118 CFNetwork/1408.0.4 Darwin/22.5.0");
        client.println("Content-Length: 105");
        client.println();
        client.println("{\"alertRequest\":{ \"action\": [\"Flash\"], \"delay\": 0, \"duration\": 1, \"override\": [\"DoorOpen\",\"IgnitionOn\"]}}");
        break;
      }

      // DIAGNOSTICS NEW
      case 6: {
        Serial.println("sendRequest 6");
        client.print("POST /api/gmone/v1/vehicle/performVehicleChargingMetricsQuery?vehicleVin=");
        client.print(vin);
        client.println(" HTTP/1.1");
        client.println("Accept-Encoding: br, gzip, deflate");
        client.println("Accept-Language: en-US");
        client.println("Connection: keep-alive");
        client.println("Content-Type: application/x-www-form-urlencoded");
        client.println("Host: eve-vcn.ext.gm.com");
        client.println("User-Agent: myChevrolet/8006 CFNetwork/3826.600.41 Darwin/24.6.0");
        client.println("Content-Length: 83");
        client.print("X-Gm-Token: ");
        client.println(gmToken);
        client.print("X-Gm-Mobiletoken: ");
        client.println(accessToken);
        client.println();
        client.print("vehicleId=");
        client.print(vid);
        client.println("&refreshTrigger=useEvVehicleTelemetry");
        break;
      }

      // COMMAND RESULT
      case 7: {
        Serial.println("sendRequest 7");
        client.print("GET /api/v1/account/vehicles/");
        client.print(vin);
        client.print("/requests/");
        client.print(commandID);
        client.println(" HTTP/1.1");
        client.println("Accept: application/json");
        client.println("Accept-Encoding: br, gzip, deflate");
        client.println("Accept-Language: en-US");
        client.print("Authorization: Bearer ");
        client.println(accessToken);
        client.println("Connection: keep-alive");
        client.println("Content-Type: application/json; charset=UTF-8");
        client.println("Host: na-mobile-api.gm.com");
        client.println("User-Agent: myChevrolet/118 CFNetwork/1408.0.4 Darwin/22.5.0");
        client.println();
        break;
      }

      // REFRESH/SUBJECT TOKEN
      case 8: {
        Serial.println("sendRequest 8");
        client.println("POST /gmb2cprod.onmicrosoft.com/b2c_1a_seamless_mobile_signuporsignin/oauth2/v2.0/token HTTP/1.1");
        client.println("Accept: application/json");
        client.print("Client-Request-Id: ");
        client.println(clientRequestID);
        client.print("Content-Length: ");
        client.println(refreshTokenLength + 279);
        client.println("Content-Type: application/x-www-form-urlencoded");
        client.println("Host: custlogin.gm.com");
        client.println("Return-Client-Request-Id: true");
        client.println("User-Agent: myChevrolet/118 CFNetwork/1408.0.4 Darwin/22.5.0");
        client.println();
        client.print("client_id=");
        client.print(clientID);
        client.print("&scope=https%3A%2F%2Fgmb2cprod.onmicrosoft.com%2F3ff30506-d242-4bed-835b-422bf992622e%2FTest.Read+openid+profile+offline_access&refresh_token=");
        client.print(refreshToken);
        client.println("&redirect_uri=msauth.com.gm.myChevrolet%3A%2F%2Fauth&client_info=1&grant_type=refresh_token");
        break;
      }

      // ACCESS TOKEN
      case 9: {
        Serial.println("sendRequest 9");
        client.println("POST /sec/authz/v3/oauth/token HTTP/1.1");
        client.println("Accept-Language: en-US");
        client.println("Appversion: OMB_CVY_IOS_7.1.0");
        client.print("Content-Length: ");
        client.println(subjectTokenLength + 262);
        client.println("Content-Type: application/x-www-form-urlencoded");
        client.println("Host: na-mobile-api.gm.com");
        client.println("User-Agent: myChevrolet/118 CFNetwork/1408.0.4 Darwin/22.5.0");
        client.println();
        client.print("grant_type=urn%3Aietf%3Aparams%3Aoauth%3Agrant-type%3Atoken-exchange&subject_token=");
        client.print(subjectToken);
        client.print("&subject_token_type=urn%3Aietf%3Aparams%3Aoauth%3Atoken-type%3Aaccess_token&scope=msso+role_owner+priv+onstar+gmoc+user+user_trailer&device_id=");
        client.println(deviceID);
        break;
      }
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

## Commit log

2025-05-28 Removed unused variables, fixed secret references
    [OnStarduino.ino]
2025-05-29 SMS error tweaks, reset command queue on error
    [OnStarduino.ino]
2025-06-04 Readme improvements, added assembly resources
    [AluminumFront.step, Counter_Cuff.3mf, Counter_Frame.3mf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]
